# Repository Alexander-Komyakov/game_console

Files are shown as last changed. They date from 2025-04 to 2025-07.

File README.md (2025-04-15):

## Игровая консоль

Игровая консоль включает в себя:
 - Схему платы в проекте KiCad
 - 3Д модель
 - программное обеспечение https://gitlab.3dprintlite.ru/esp32/dt240x320

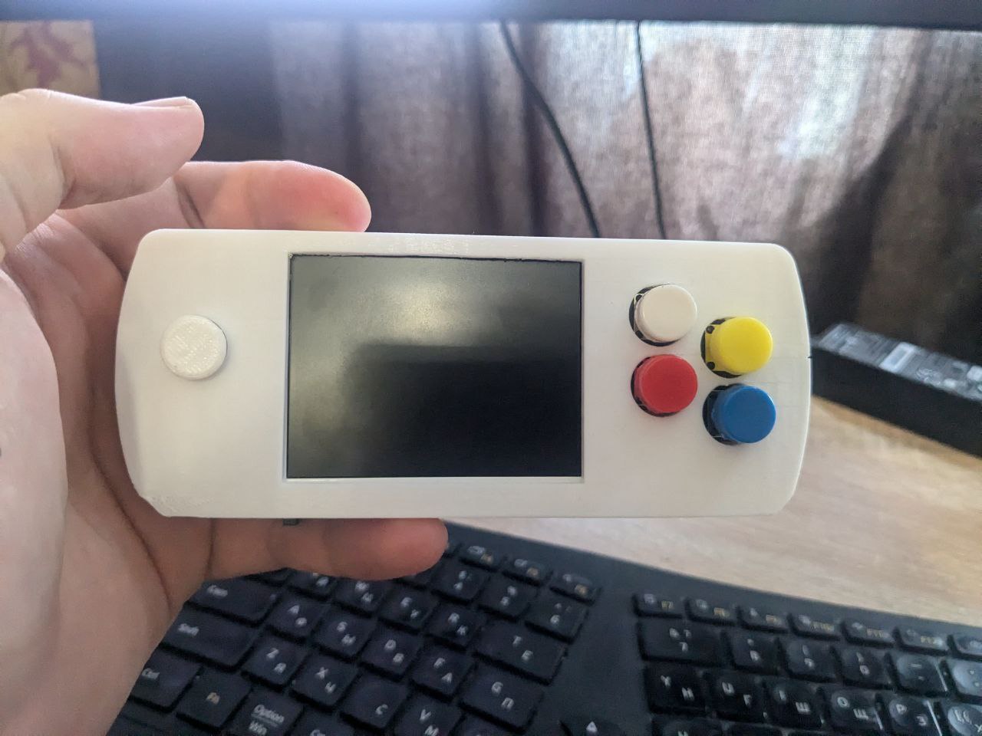
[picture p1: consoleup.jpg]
Консоль фото 1

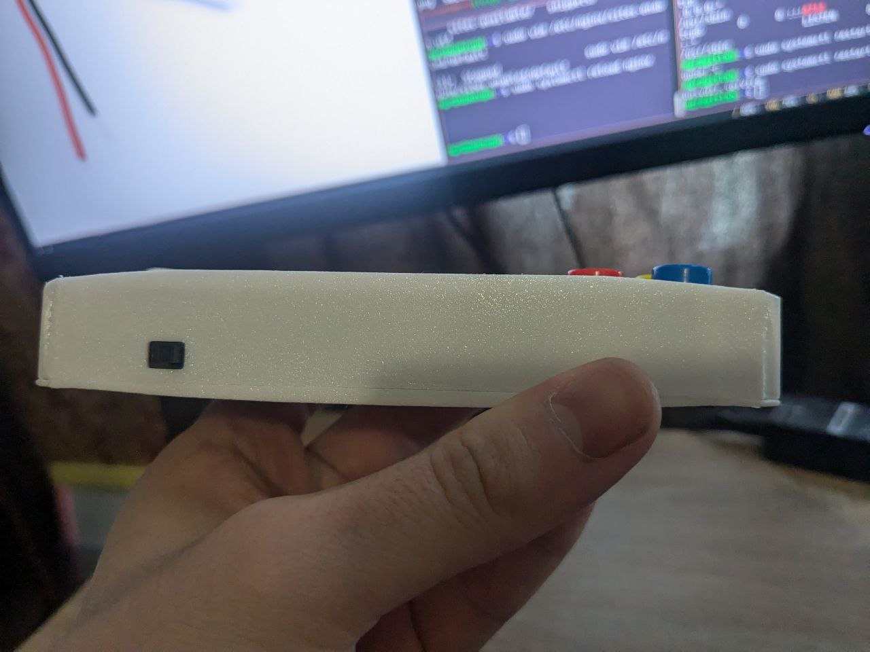
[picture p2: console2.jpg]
Консоль фото 2

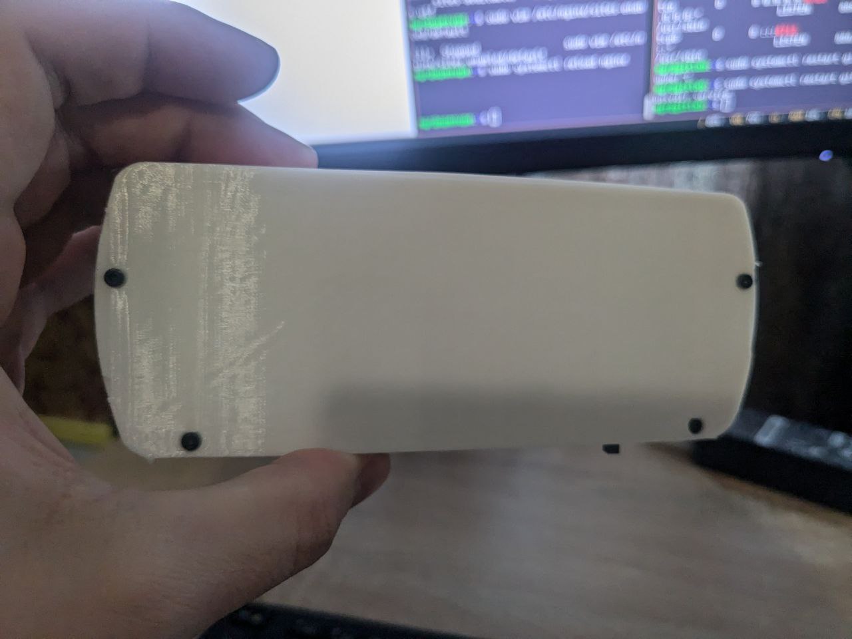
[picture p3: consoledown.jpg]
Консоль фото 3

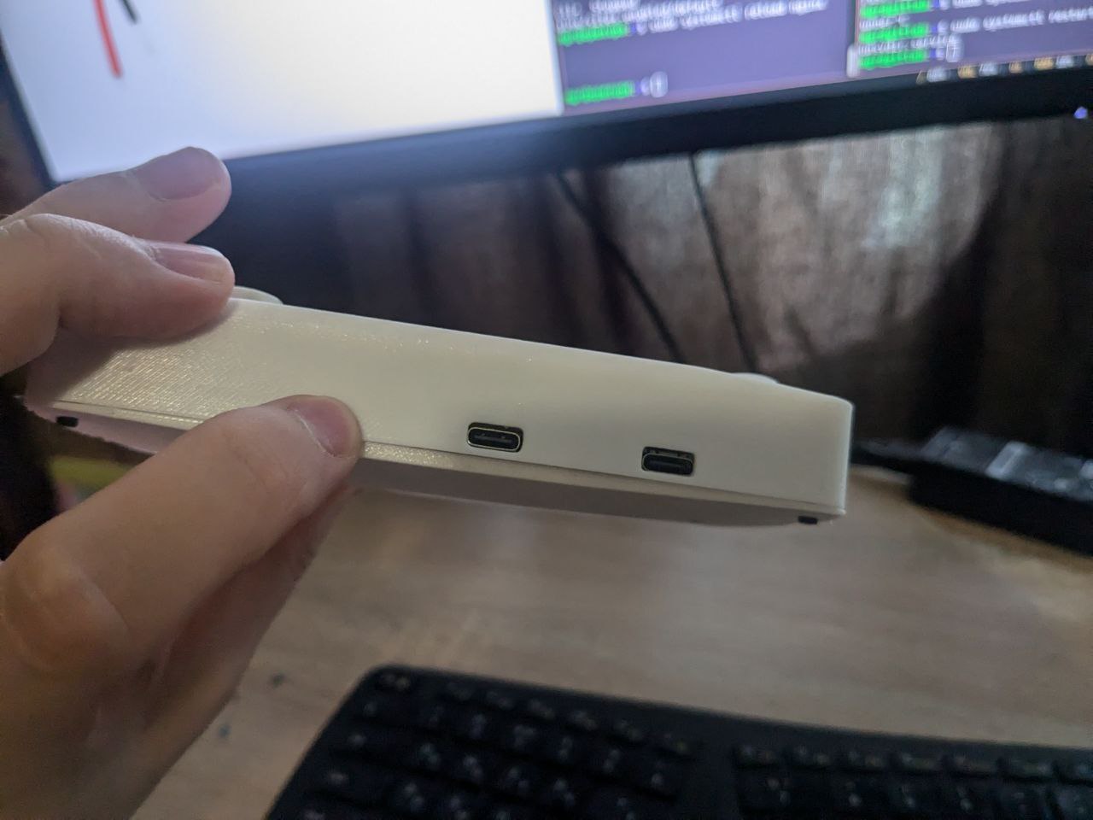
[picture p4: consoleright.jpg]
Консоль фото 4


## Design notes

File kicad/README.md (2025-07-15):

Для изготовления печатной платы я использовал CNC 3018 MAX, полностью металлическую версию.

`Версия KiCad 9.0.0-9.0.0-2 ubuntu 24`

На основной плате видно, что мы используем ESP32-WROOM-32 с 520кб ОЗУ и 4мб FLASH.

К ней подключен по SPI ST7789V 240x320, шлейфом 18 пин, 5-ти позиционной кнопке и четырем обычным кнопкам.
Для получения дисплея как в нашем проекте нужно снять с красной платы дисплей для этого.
Будьте осторожны, шлейф очень хрупкий. Лучше работать феном и медленно, без большой нагрузки отодвигать шлейф со своего посадочного места для дальнейшего закрепления на нашей печатной плате.

Для сборки понадобится:
 - Текстолит односторонний больше чем 130x60мм
 - ESP32-WROOM-32 4мб flash, 520 КБ ОЗУ без PSRAM
 - TP4056
 - Аккумулятор 1000мач, 3.7В https://aliexpress.ru/item/4000939317595.html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
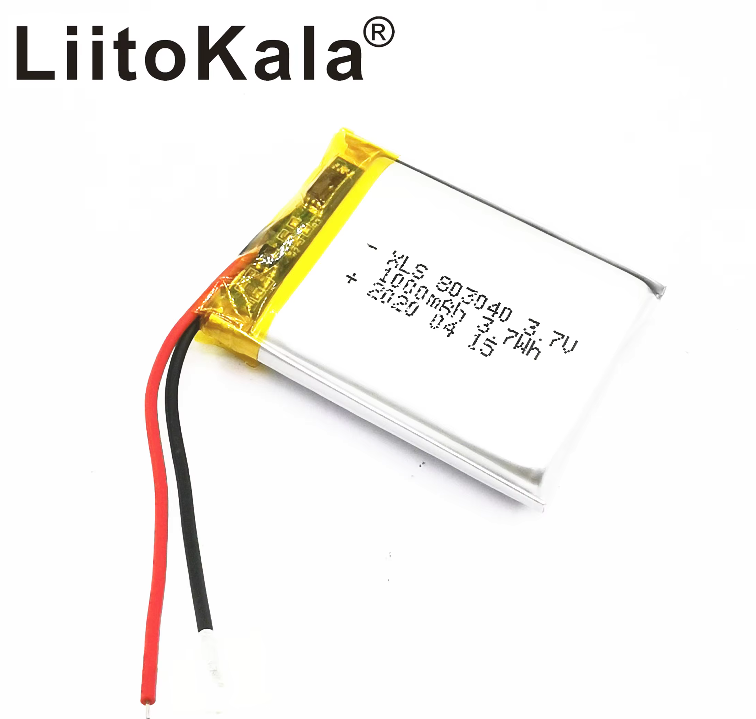
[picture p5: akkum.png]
Аккумулятор

 - Тактовые кнопки, 4 шт. Размер: 12*12*7,3 мм
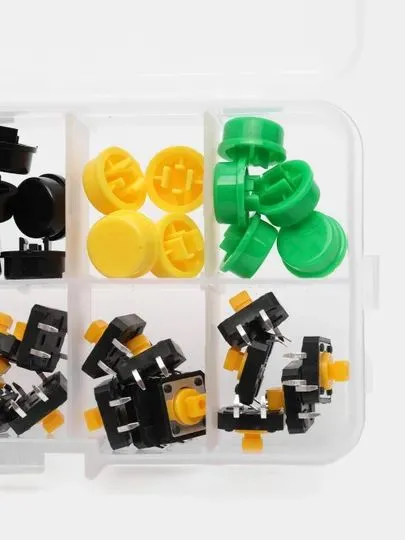
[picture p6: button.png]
Кнопки

 - Пяти позиционная кнопка https://aliexpress.ru/item/1005008348341984.html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
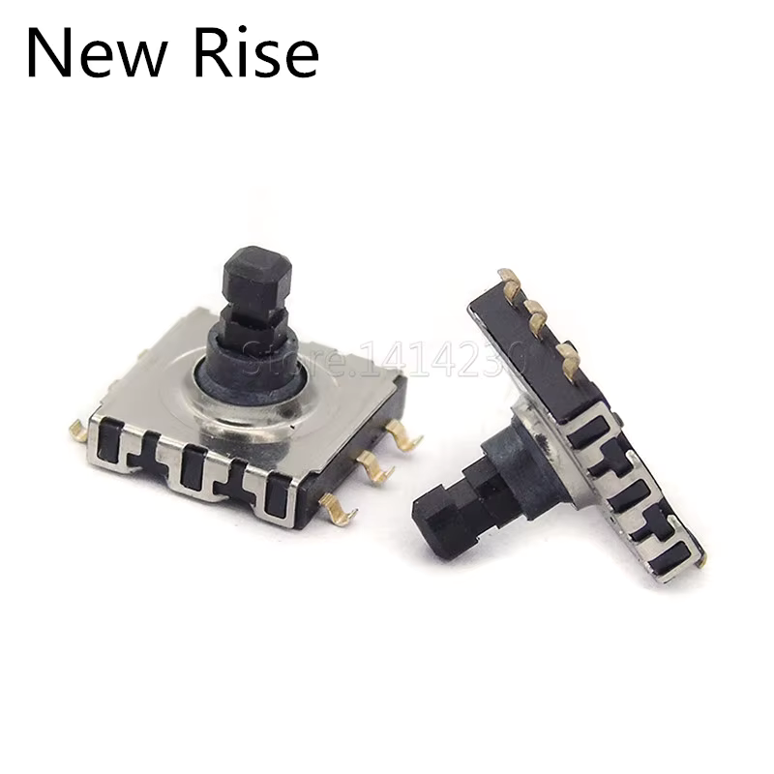
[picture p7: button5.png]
Кнопки 5-типоз

 - Переключатель питания https://www.ozon.ru/product/vyklyuchatel-dvizhkovyy-polzunkovyy-pereklyuchatel-10-sht-1323063165/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
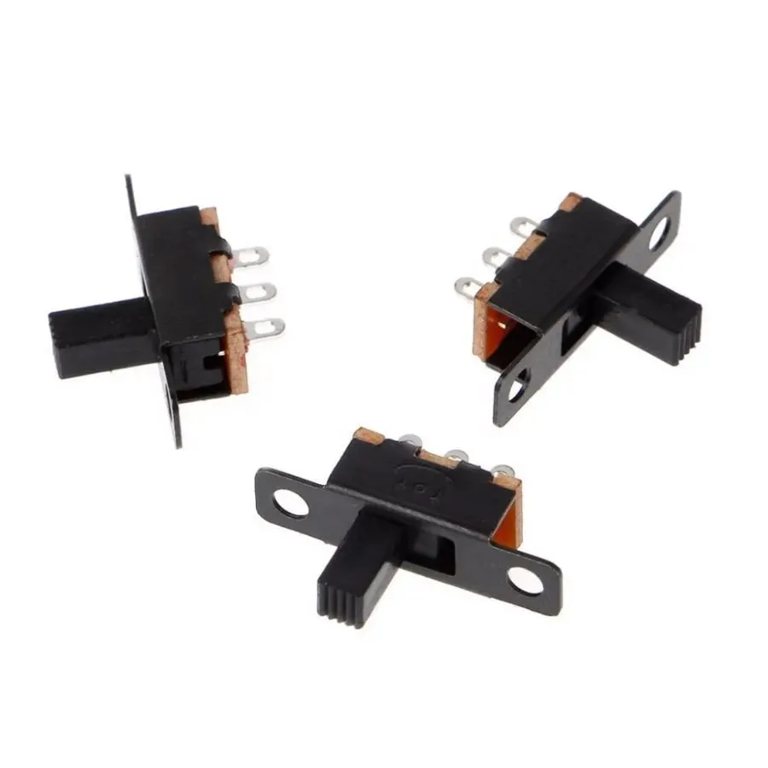
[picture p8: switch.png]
Кнопки питания

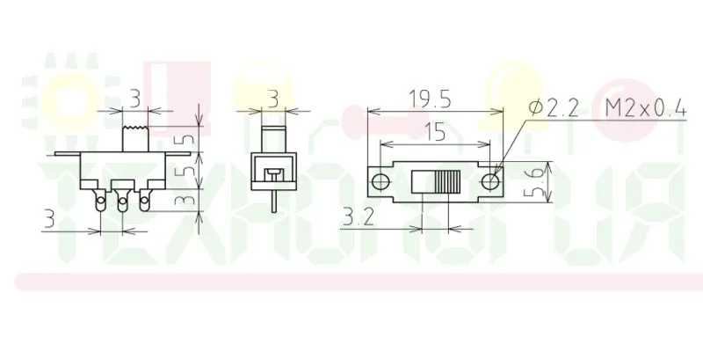
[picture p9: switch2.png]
Кнопки питани схема


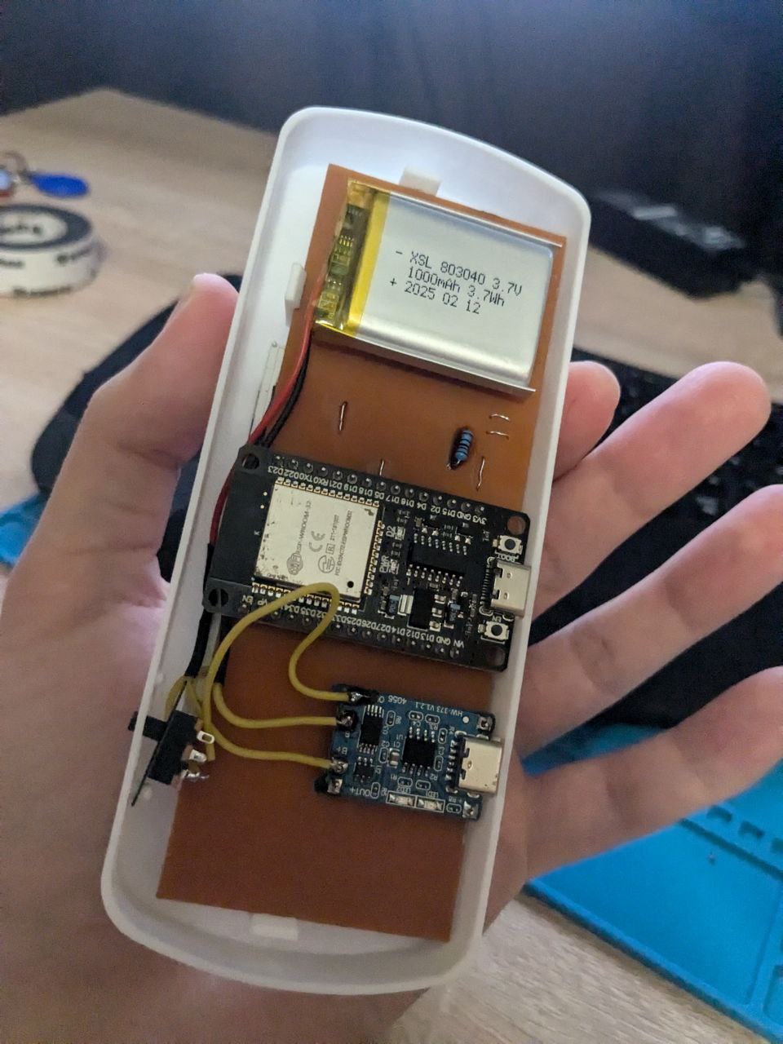
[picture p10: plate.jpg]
Плата снизу

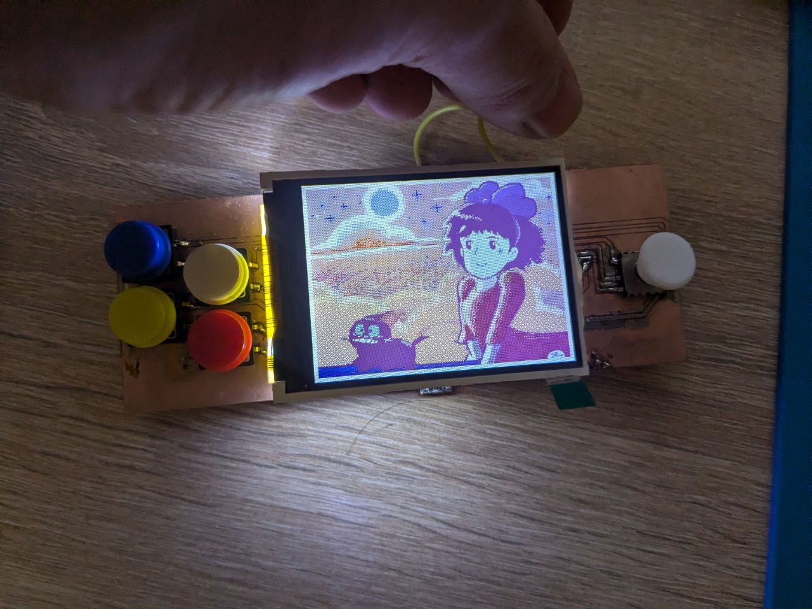
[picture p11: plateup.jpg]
Плата сверху


`Версия pcb2gcode`

```
pcb2gcode --version
2.5.0
Git commit:
Boost: 107400
Gerbv: 2.10.0
Geos: Not installed
```

Конфиг лежит в config.ini

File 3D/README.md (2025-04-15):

## 3д модели

Разработано в FreeCad 1.0

2 модели, основная часть корпуса и нижняя часть.

Скрепляются болтами m2x8. M2 сложно напечатать на FDM 3д принтере, поэтому модель не прикладываю, а предлагаю купить металлические.

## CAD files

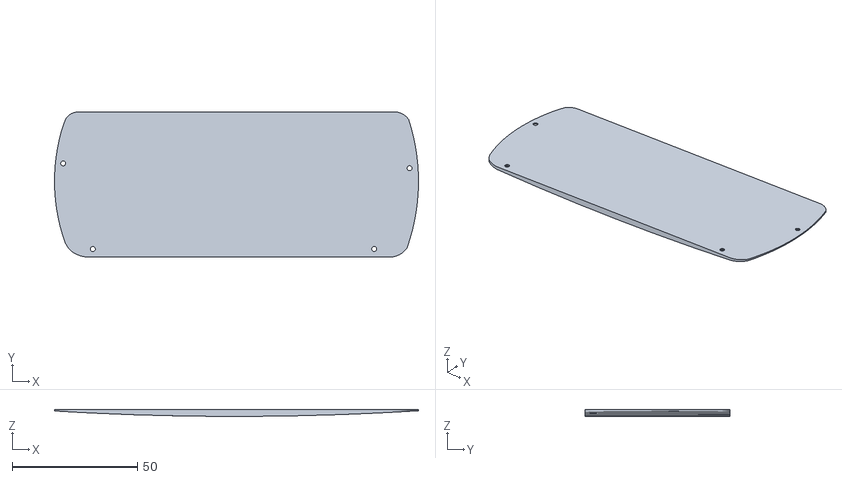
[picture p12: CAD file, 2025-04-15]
3D/down.stl
145.2 x 57.9 x 2.79

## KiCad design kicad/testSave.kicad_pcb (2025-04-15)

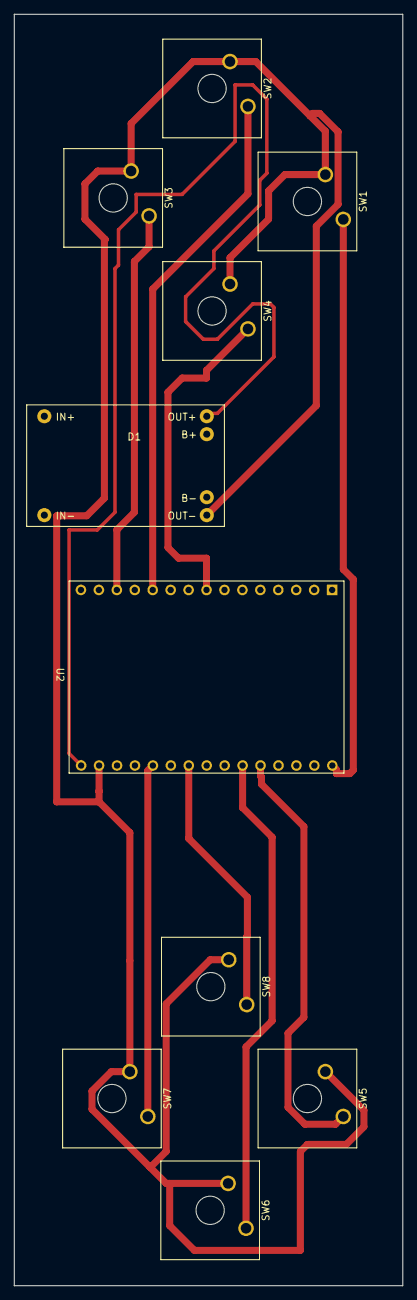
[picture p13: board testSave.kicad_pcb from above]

Board: 2 copper layers, 55.0 x 180.0 mm, 10 parts (0 on the bottom side), 8 nets.

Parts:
D1: TP4056-Module
SW1, SW2, SW3, SW4, SW5, SW6, SW7, SW8: SW_Push; SW_Cherry_MX_1.00u_Plate
U2: ESP32-S3-WROOM-1; ESP32-Wroom-32

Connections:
unnamed: D1.3, U2.16 (IO46), U2.26 (IO45)
unnamed: D1.4, SW1.2, SW2.2, SW3.2, SW4.2, SW5.2, SW6.2, SW7.2, SW8.2, U2.1 (GND), U2.GND
unnamed: SW2.1, U2.19 (IO11)
unnamed: SW1.1, U2.21 (IO13)
unnamed: SW7.1, U2.22 (IO14)
unnamed: SW8.1, U2.25 (IO48)
unnamed: SW5.1, U2.14 (USB_D+)
unnamed: SW6.1, U2.13 (USB_D-)

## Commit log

2025-04-15 init game console
    [Bolt.stl, down.stl]
2025-04-15 add readme & remove bolt
    [Bolt.stl]
2025-04-15 add kicad
    [down.stl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]
2025-04-18 update scheme; add gnd tp4056 button
    [test.kicad_pcb]
2025-07-10 slim version
    [test.kicad_pcb]
2025-07-15 update plate
    [test.kicad_pcb]
2025-07-15 pcb2gcode add
2025-07-31 update kicad plate
    [test-B_Cu.gbl, test-B_Cu.gbr, test-B_Mask.gbr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]
2025-08-01 fix plate
    [test.kicad_pcb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]
2025-09-03 update kicad scheme version. Add EN to 3V3 drill and jtag change to uart
    [test.kicad_pcb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]
2025-09-09 add more text in kicad
    [test.kicad_pcb]
